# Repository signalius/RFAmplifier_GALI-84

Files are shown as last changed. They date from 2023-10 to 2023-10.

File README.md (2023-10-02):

## GALI-84+ RF Amplifier
* Impedance 50 ohm is calculated for FR4 0.8mm
* Maximum frequency is 6GHz (I tested only to 4GHz)

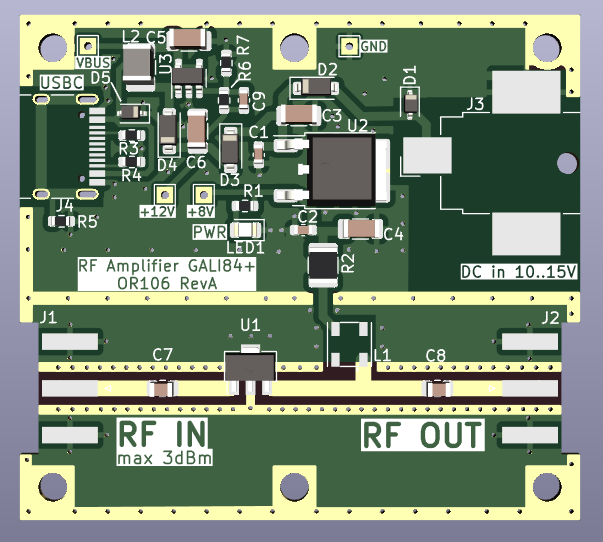
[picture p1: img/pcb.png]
pcb


schematic

## LICENSE
GNU General Public License v3.0

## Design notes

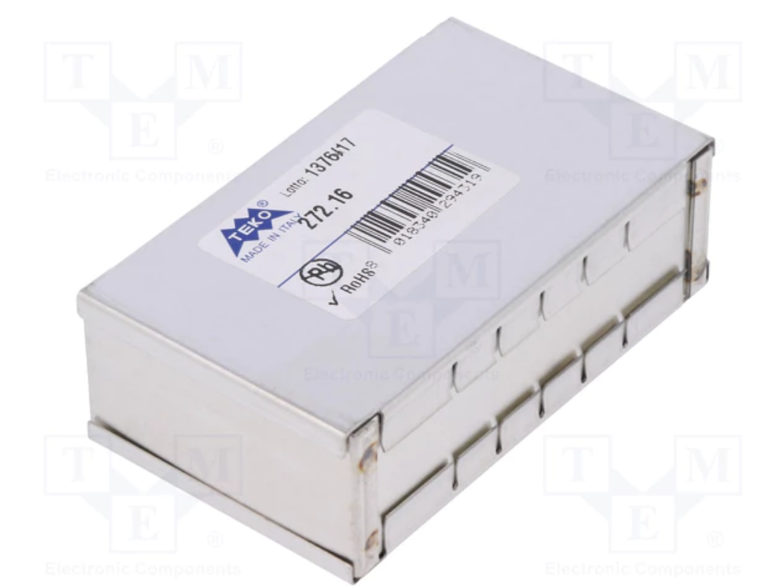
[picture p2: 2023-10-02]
doc/TEKO Obudowa z TME 371.16.png

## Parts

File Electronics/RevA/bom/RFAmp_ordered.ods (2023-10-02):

 | Sourced | Price USD at 10 | Price tot | Qty | References | Value | Footprint | MPN | MF
1 | mouser | 0,141 | 0,564 | 4 | C3, C4, C5, C6 | 10u | C_1206_3216Metric | GRM31CR71E106KA12L | Murata
2 | mouser | 0,027 | 0,054 | 2 | C1, C2 | 100n | C_0603_1608Metric
3 | mouser | 0,056 | 0,112 | 2 | C7, C8 | 2400p | C_0805_2012Metric
4 | mouser | 0,028 | 0,028 | 1 | C9 | 4.7p | C_0603_1608Metric
5 | mouser | 0,072 | 0,144 | 2 | R3, R4 | 5k1 | R_0603_1608Metric
6 |  |  | 0 | 1 | R1 | 2k7 | R_0603_1608Metric
7 | mouser | 0,167 | 0,167 | 1 | R2 | 22R 0.75W | R_1210_3225Metric
8 | mouser | 0,068 | 0,068 | 1 | R5 | 1M | R_0603_1608Metric
9 | mouser | 0,072 | 0,072 | 1 | R6 | 1.8M | R_0603_1608Metric
10 | mouser | 0,019 | 0,019 | 1 | R7 | 205k | R_0603_1608Metric
11 | mouser | 4,79 | 4,79 | 1 | L1 | TCCH-80+ | TCCH-80+ | TCCH-80+ | Mini-Circuits
12 | mouser | 0,23 | 0,23 | 1 | L2 | 6.8uH | L_1210_3225Metric_Pad1.42x2.65mm_HandSolder | LQH32MN6R8K23L | Murata
13 | mouser | 0,27 | 0,81 | 3 | D2, D3, D4 | MBR0530 | D_SOD-123 | MBR0530T1G | Onsemi
14 | mouser | 0,329 | 0,329 | 1 | D1 | 15V ESD | D_SOD-323 | PESD15VL1BA | Nexperia
15 | mouser | 0,3 | 0,3 | 1 | D5 | 5V ESD | D_SOD-323 | PESD5V0L1BA,115 | Nexperia
16 | mouser | 3,06 | 3,06 | 1 | U1 | GALI-84 | SOT-89-3 | GALI-84 | Mini-Circuits
17 | mouser | 0,65 | 0,65 | 1 | U2 | 78M08 | TO-252-2 | L78M08ABDT | ST
18 | mouser | 0,9 | 0,9 | 1 | U3 | TPS61041DBV | SOT-23-5 | TPS61041DBV | TI
19 | mouser | 0,18 | 0,18 | 1 | LED1 | RED | LED_0805_2012Metric | 150080RS75000 | Wurth
20 | china | 0,4 | 0,8 | 2 | J1, J2 | SMA | SMA_Amphenol_132289_EdgeMount
21 | mouser | 1,18 | 1,18 | 1 | J3 | PJ-036AH | BarrelJack_CUI_PJ-036AH-SMT_Horizontal | PJ-036AH | CUI
22 | lcsc | 0,22 | 0,22 | 1 | J4 | TYPE-C-31-M-12 | USB_C_Receptacle_HRO_TYPE-C-31-M-12 | TYPE-C-31-M-12 | Korean Hroparts
23 | tme |  | 0 | 1 | enclosure
24 | jlcpcb | 4,2 | 4,2 | 1 | pcb
 |  | Total price | 18,877

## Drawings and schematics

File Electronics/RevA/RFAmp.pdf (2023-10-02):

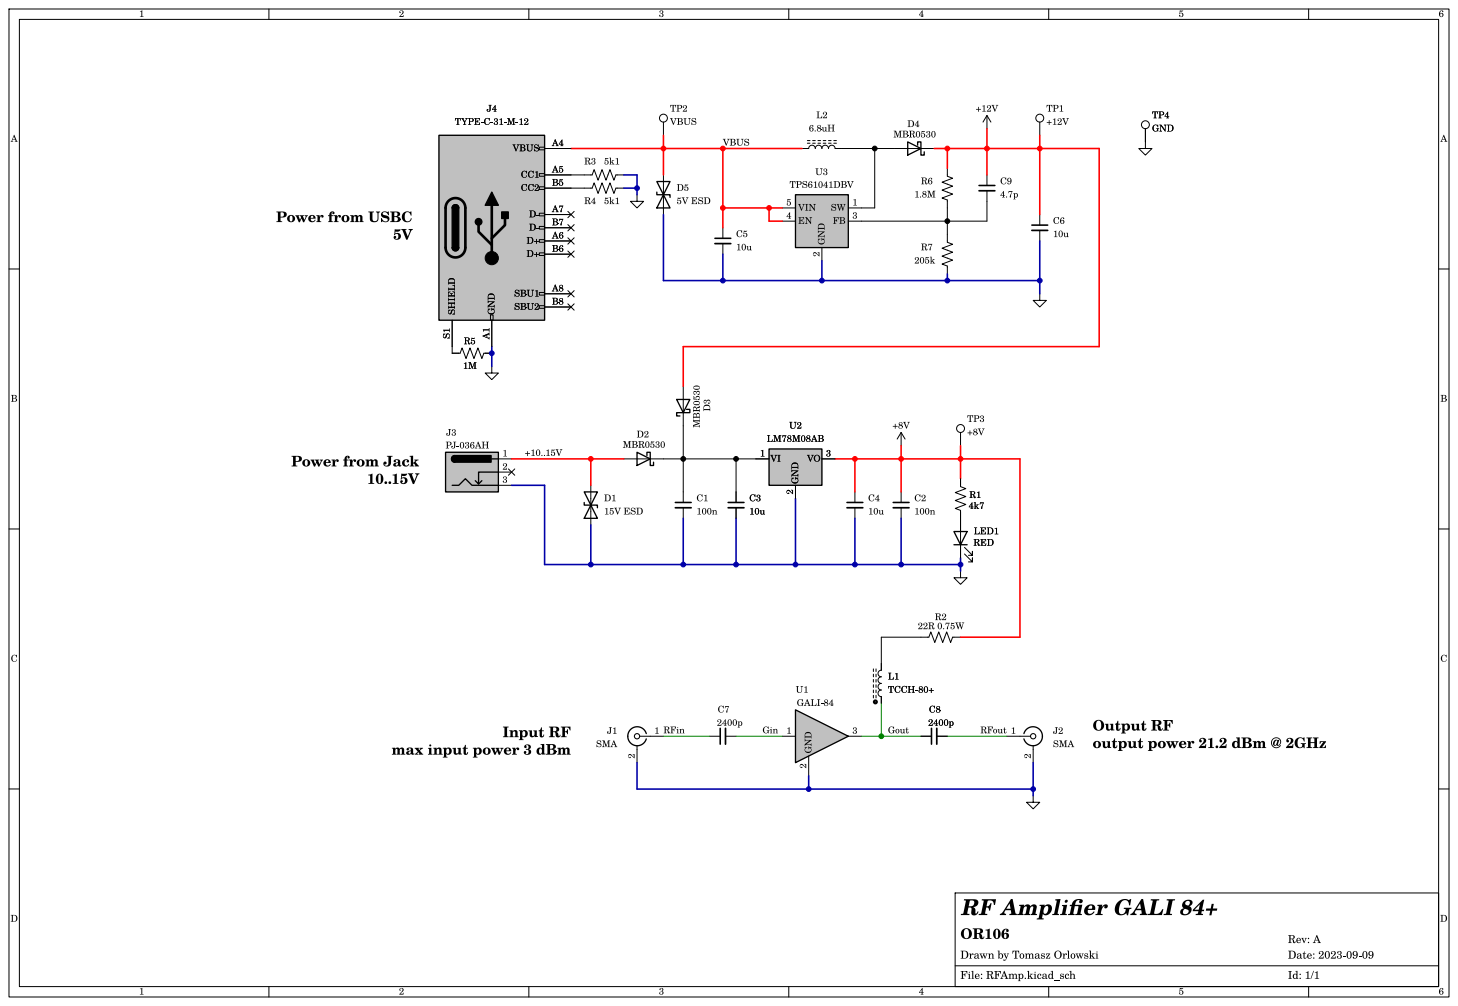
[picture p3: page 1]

Input RF max input power 3 dBm

Id: 1/1 RF Amplifier GALI 84+

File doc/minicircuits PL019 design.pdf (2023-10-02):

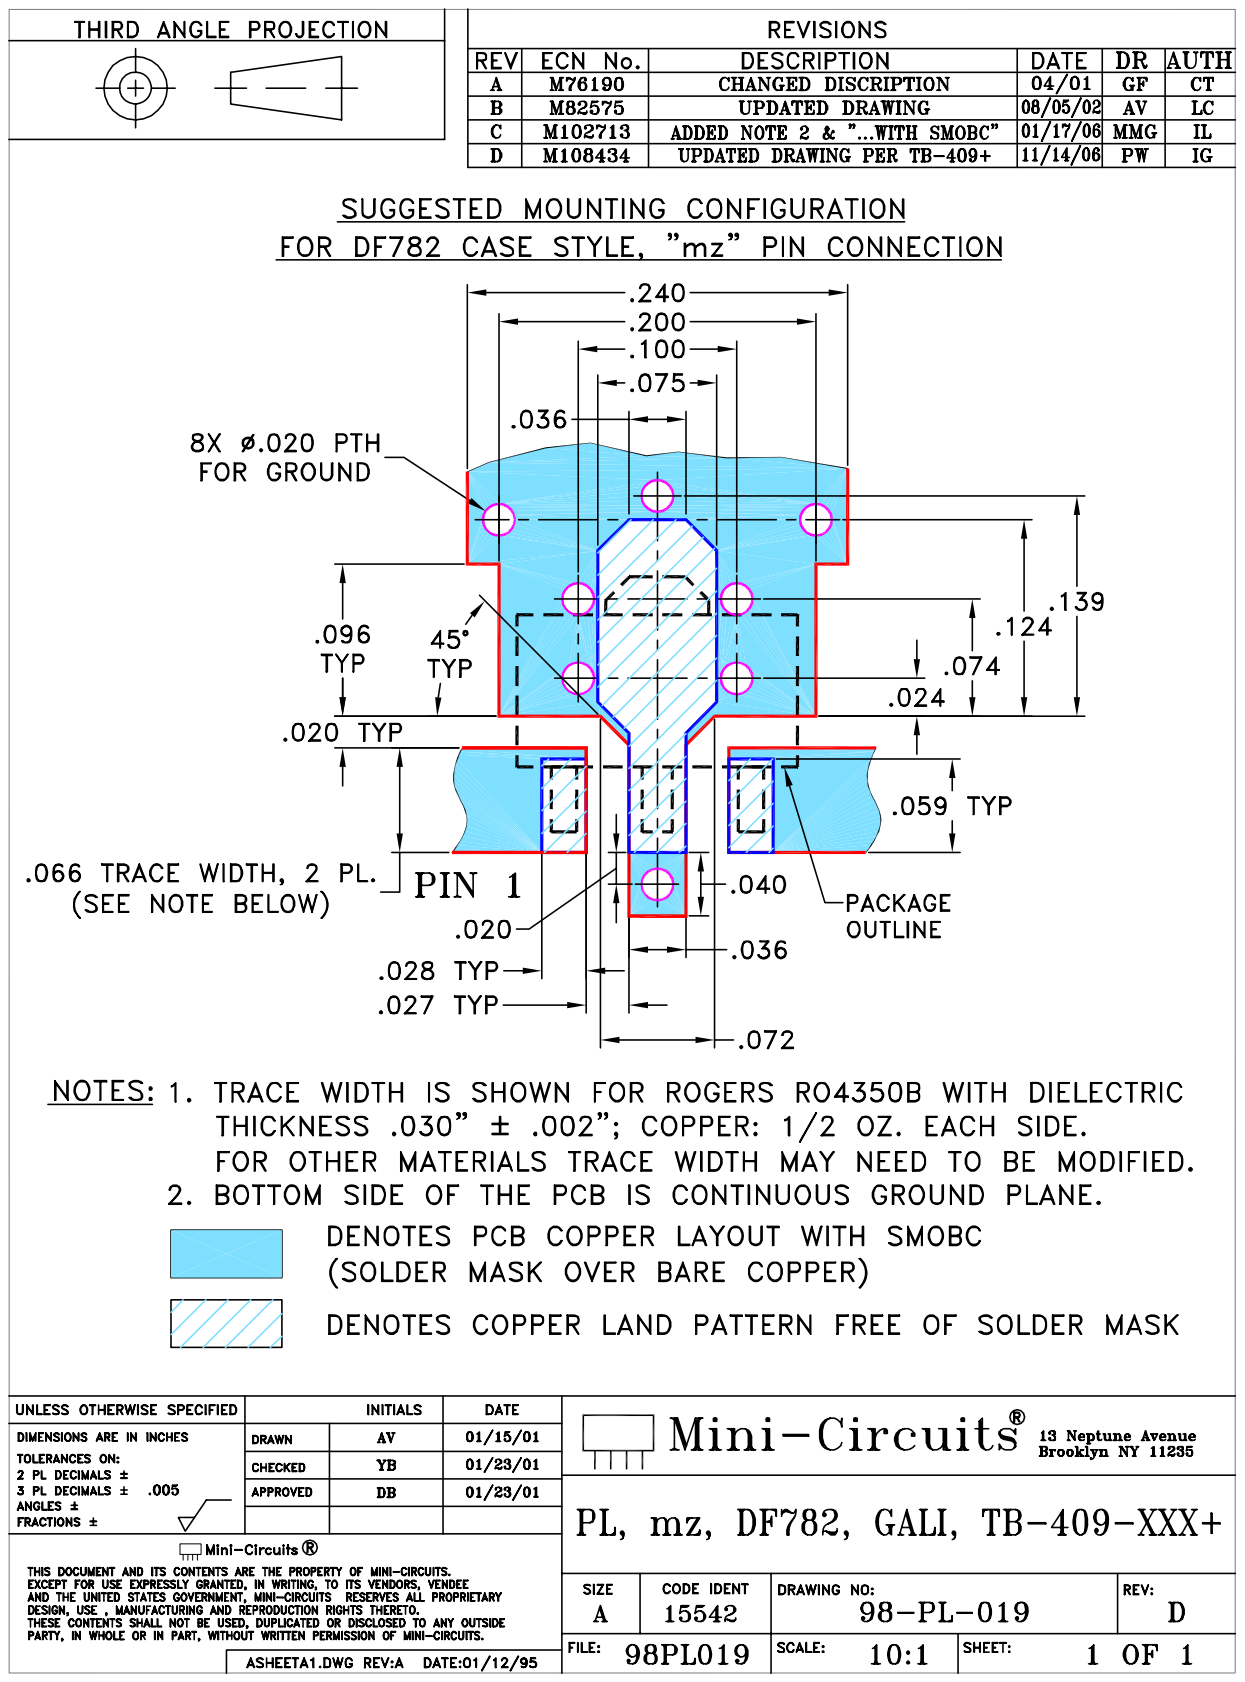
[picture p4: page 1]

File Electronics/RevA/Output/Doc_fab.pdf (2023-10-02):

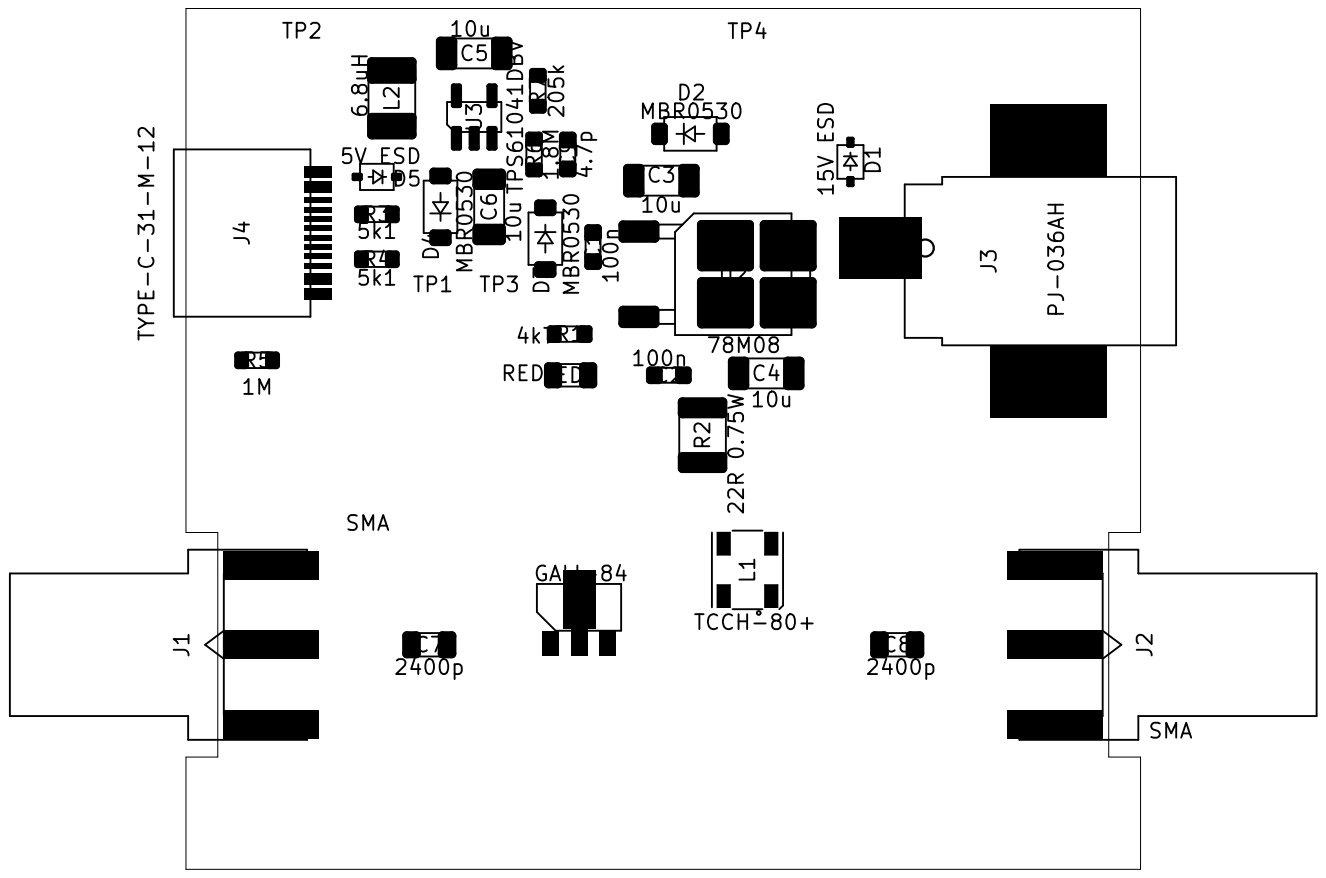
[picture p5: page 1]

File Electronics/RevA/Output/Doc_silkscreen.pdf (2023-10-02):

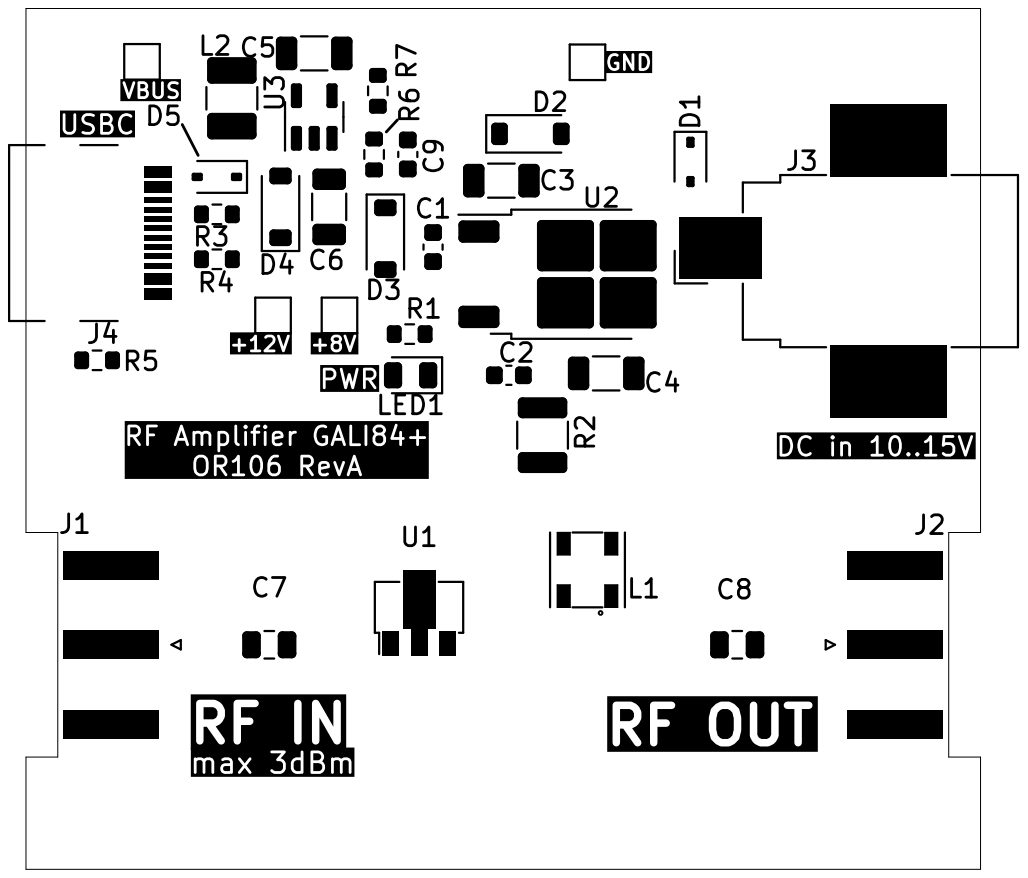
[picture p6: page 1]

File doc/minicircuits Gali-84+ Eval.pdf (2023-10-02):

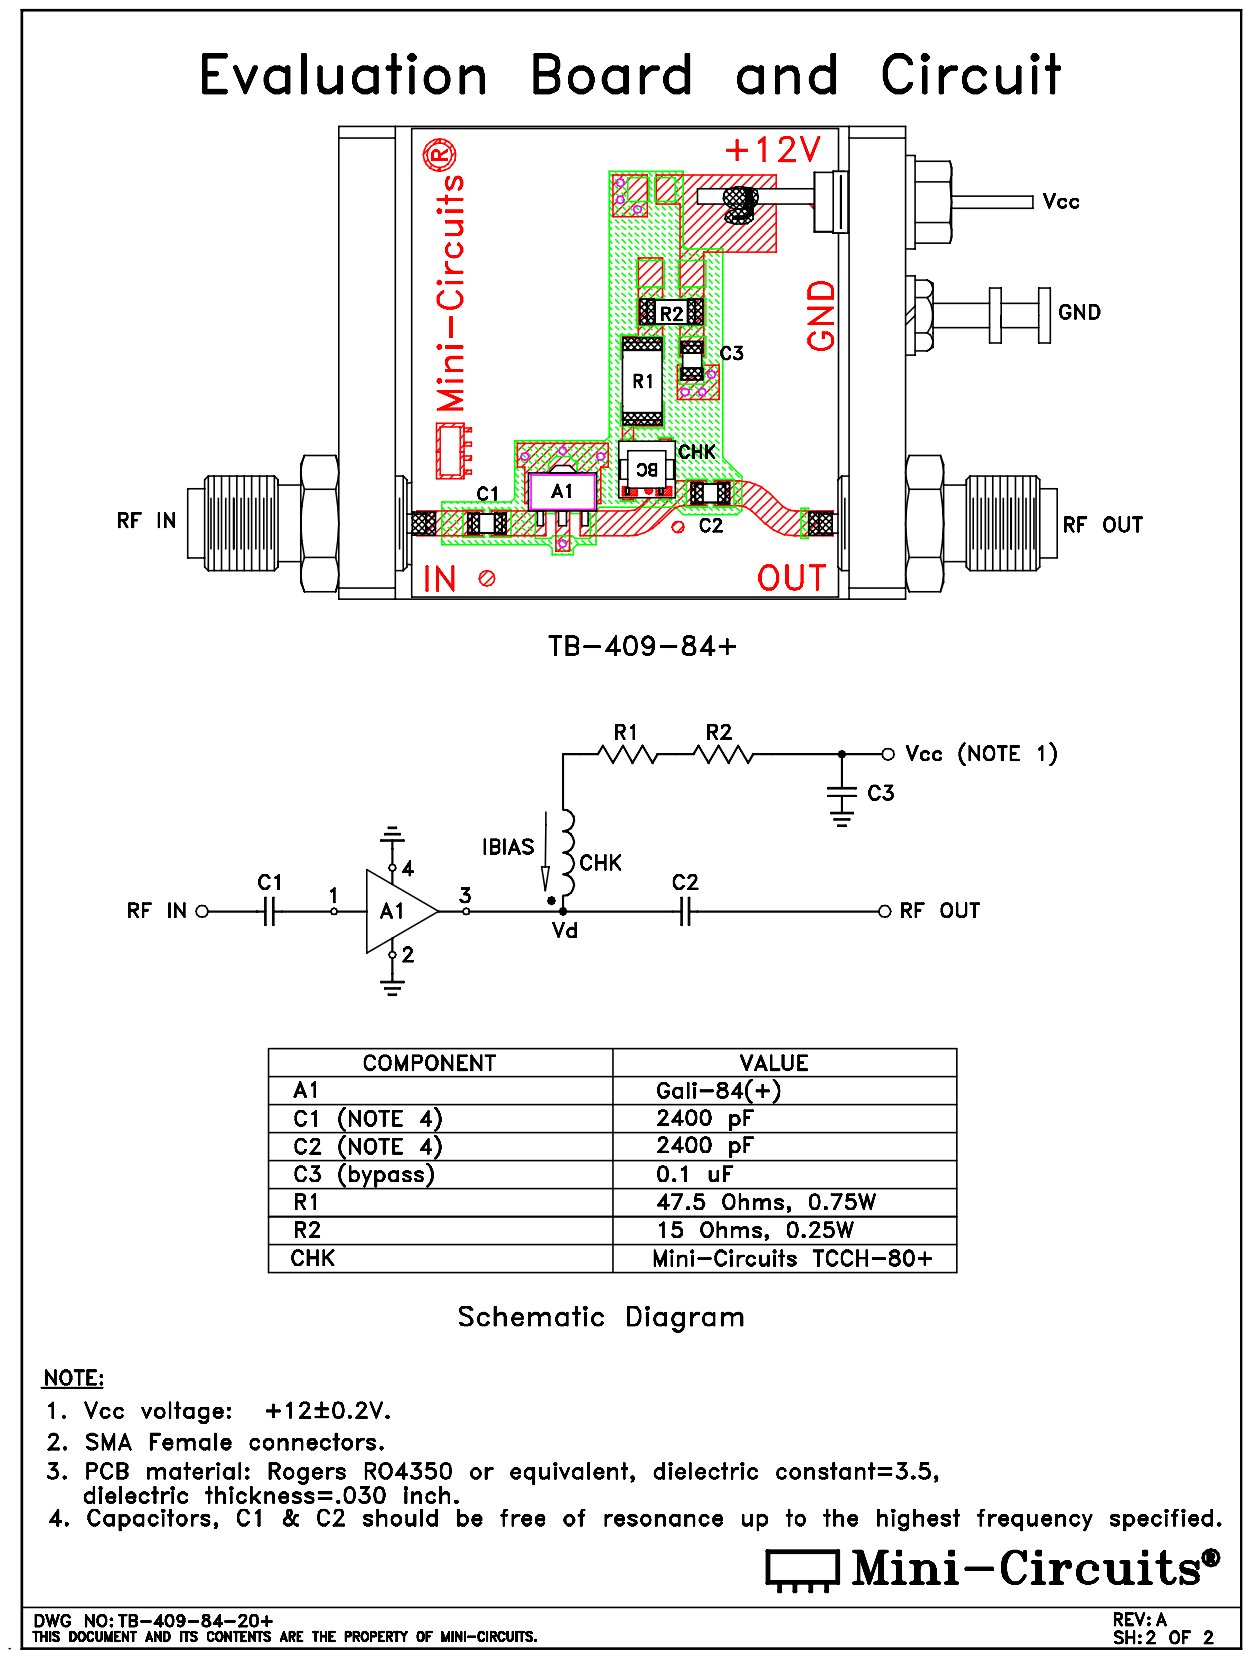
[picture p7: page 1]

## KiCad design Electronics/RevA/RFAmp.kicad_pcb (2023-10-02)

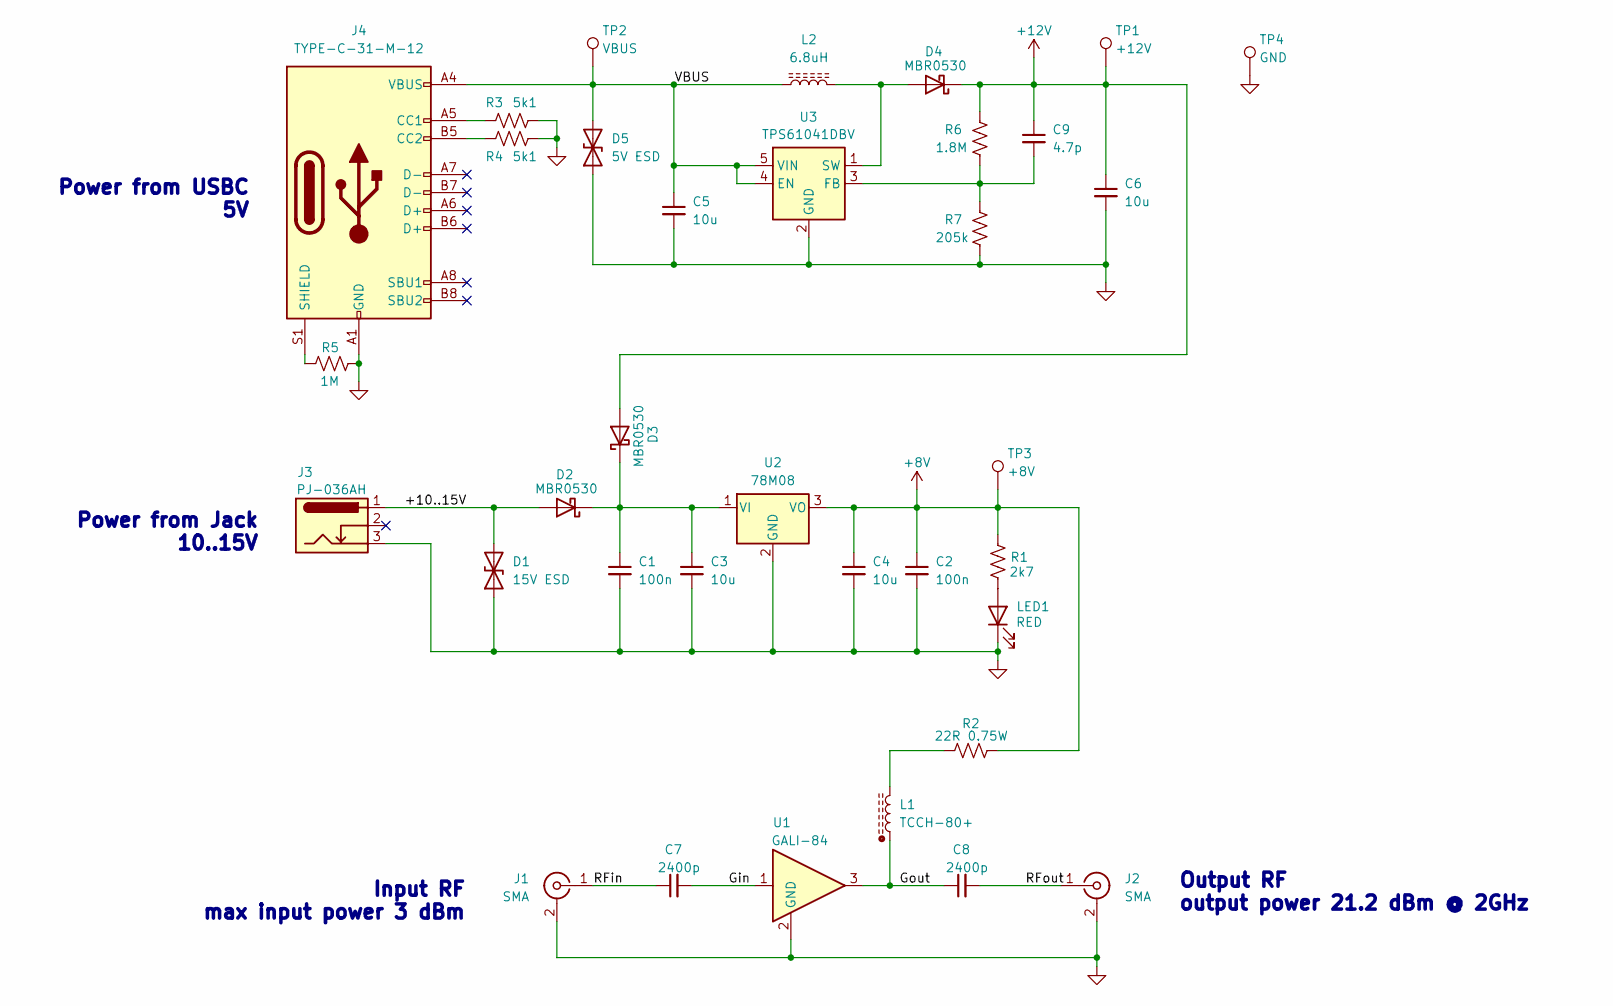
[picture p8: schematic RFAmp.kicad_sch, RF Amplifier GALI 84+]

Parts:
C1, C2: 100n; C_0603_1608Metric
C3, C4, C5, C6: 10u; C_1206_3216Metric; MPN GRM31CR71E106KA12L
C7, C8: 2400p; C_0805_2012Metric; MPN GRM2165C1H242JA01D
C9: 4.7p; C_0603_1608Metric; MPN CC0603CPNPO9BN4R7
D1: 15V ESD; D_SOD-323; MPN PESD15VL1BA
D2, D3, D4: MBR0530; D_SOD-123; MPN MBR0530T1G
D5: 5V ESD; D_SOD-323; MPN PESD5V0L1BA,115
J1, J2: SMA; SMA_Amphenol_132289_EdgeMount
J3: PJ-036AH; BarrelJack_CUI_PJ-036AH-SMT_Horizontal; MPN PJ-036AH
J4: TYPE-C-31-M-12; USB_C_Receptacle_HRO_TYPE-C-31-M-12; MPN TYPE-C-31-M-12
L1: TCCH-80+; MPN TCCH-80+
L2: 6.8uH; L_1210_3225Metric_Pad1.42x2.65mm_HandSolder; MPN LQH32MN6R8K23L
LED1: RED; LED_0805_2012Metric; MPN 150080RS75000
R1: 2k7; R_0603_1608Metric
R2: 22R 0.75W; R_1210_3225Metric
R3, R4: 5k1; R_0603_1608Metric
R5: 1M; R_0603_1608Metric
R6: 1.8M; R_0603_1608Metric
R7: 205k; R_0603_1608Metric
TP1: +12V; TestPoint_THTPad_1.5x1.5mm_Drill0.7mm
TP2: VBUS; TestPoint_THTPad_1.5x1.5mm_Drill0.7mm
TP3: +8V; TestPoint_THTPad_1.5x1.5mm_Drill0.7mm
TP4: GND; TestPoint_THTPad_1.5x1.5mm_Drill0.7mm
U1: GALI-84; SOT-89-3; MPN GALI-84
U2: 78M08; TO-252-2; MPN L78M08ABDT
U3: TPS61041DBV; SOT-23-5; MPN TPS61041DBV

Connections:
+8V: C2.1, C4.1, R1.1, R2.2, TP3.1, U2.3 (VO)
+12V: C6.1, C9.1, D3.2 (A), D4.1 (K), R6.1, TP1.1
/+10..15V: D1.2 (A2), D2.2 (A), J3.1
/Gin: C7.2, U1.1
/Gout: C8.1, L1.1, U1.3
/RFin: C7.1, J1.1 (In)
/RFout: C8.2, J2.1 (In)
/VBUS: C5.1, D5.2 (A2), J4.A4 (VBUS), J4.A9 (VBUS), J4.B4 (VBUS), J4.B9 (VBUS), L2.1, TP2.1, U3.4 (EN), U3.5 (VIN)
GND: C1.2, C2.2, C3.2, C4.2, C5.2, C6.2, D1.1 (A1), D5.1 (A1), J1.2 (Ext), J2.2 (Ext), J3.3, J4.A1 (GND), J4.A12 (GND), J4.B1 (GND), J4.B12 (GND), LED1.1 (K), R3.2, R4.2, R5.2, R7.2, TP4.1, U1.2 (GND), U2.2 (GND), U3.2 (GND)
unnamed: C1.1, C3.1, D2.1 (K), D3.1 (K), U2.1 (VI)
unnamed: D4.2 (A), L2.2, U3.1 (SW)
unnamed: J4.A5 (CC1), R3.1
unnamed: J4.B5 (CC2), R4.1
unnamed: J4.S1 (SHIELD), R5.1
unnamed: L1.3, R2.1
unnamed: LED1.2 (A), R1.2
unnamed: C9.2, R6.2, R7.1, U3.3 (FB)

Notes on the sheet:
Input RF max input power 3 dBm
Power from Jack 10..15V
Power from USBC 5V
Output RF output power 21.2 dBm @ 2GHz

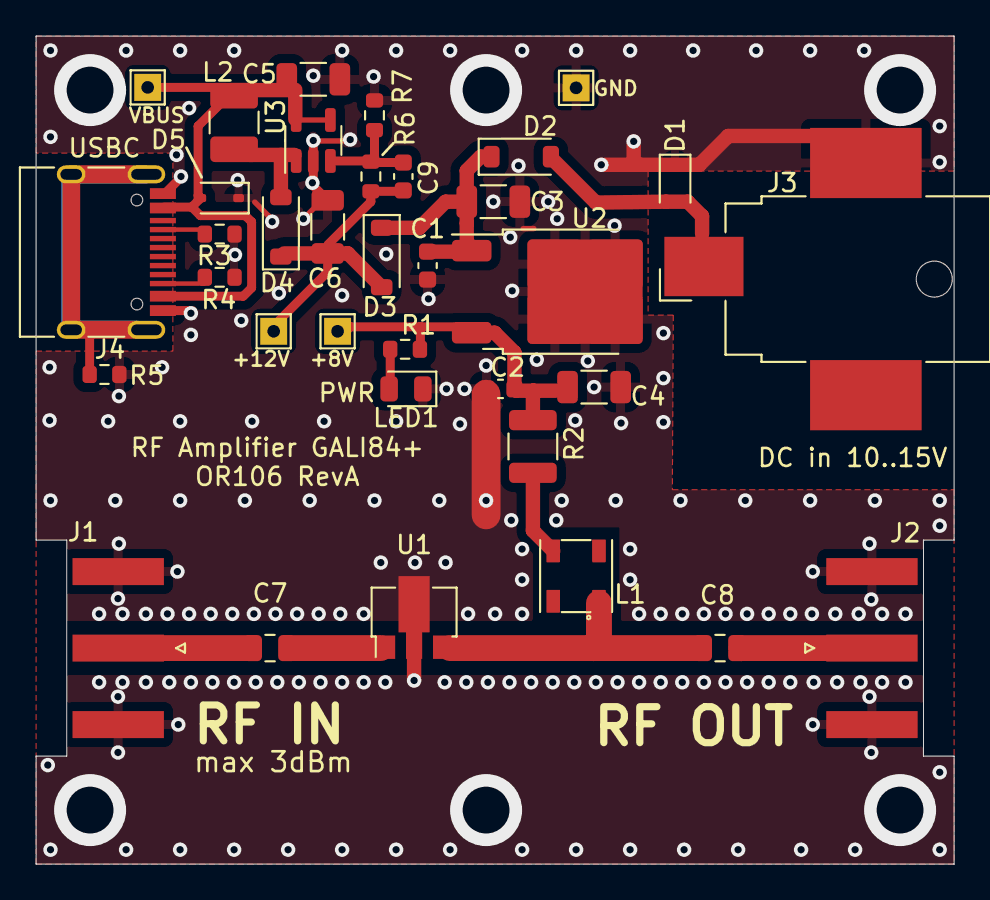
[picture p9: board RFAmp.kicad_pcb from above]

Board: 2 copper layers, 51.0 x 46.0 mm, 35 parts (0 on the bottom side), 17 nets.
